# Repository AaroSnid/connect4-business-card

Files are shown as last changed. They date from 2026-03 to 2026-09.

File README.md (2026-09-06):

# Connect 4 Business Card

This business card doubles as a portable, handheld gaming device that allows a user to play game of Connect 4 against an onboard AI bot. Built on the STM32 platform, it features a custom 7x6 bicolor LED grid and a low-leakage power system designed for maximizing battery life.

> **Status:** Hardware V1.0 Release 
> **Hardware Version:** V1.0

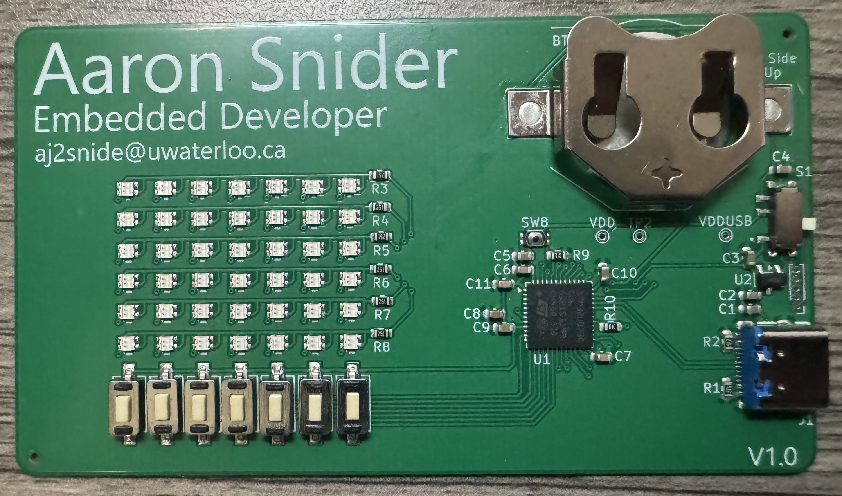
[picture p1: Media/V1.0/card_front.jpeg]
PCB V1.0 Front Image


---

## Features

- **Strategic Gameplay**
  - Play against a programmed AI bot on a microcontroller. You can select the difficulty and starting player through startup configurations.
  - 7x6 bicolor LED grid representing the game board. Player pieces are shown in Red / Orange

- **Dual Power Options**
  - **Battery Mode:** Optimized for a CR2032 coin cell for maximum portability.
  - **High-Performance Mode:** USB-C power input automatically boosts clock frequency for faster AI move processing. (Upcoming)

- **Power Management**
  - Physical slide switch for hard battery disconnection to prevent leakage current.
  - Integrated under-voltage and brown-out protection (BOR/POR/PDR).

- **Advanced Display Control**
  - 42 bicolor LEDs (84 total elements) routed antiparallel for layout efficiency.
  - Hardware-accelerated screen refreshing using timer triggered DMA writes to minimize CPU overhead.

- **Optimized Inputs**
  - 7 dedicated column buttons for move selection.
  - Software debouncing by limiting input registration windows.

---

## Bill of Materials (Summary)

| Item | Part Number | Qty | Notes |
|---|---|-----|---|
| MCU | STM32U073CCU6 | 1 | Ultra-low-power ARM Cortex-M0+ |
| Bicolor LEDs | P4-1615ROTCA1-0.6T | 42  | Red/Orange SMD LEDs |
| Battery Holder | Keystone 3002 | 1 | For CR2032 Coin Cell |
| USB-C Connector  | SHOU HAN C2765186 | 1 | 16-pin Power/Data Delivery |
| LDO Regulator | MCP1700T-3002E/TT | 1 | Low Quiescent Current 3.0V |
| Input Buttons | TSB008A2518A | 7 | Ultra-thin NO buttons |
| Power Switch | MSK12C02-HB | 1 | Battery/USB-C Selection |

---

## Hardware Subsystems

### Power Supply

- **Primary:** CR2032 Coin Cell.
- **Secondary:** USB-C (5V) regulated through an MCP1700 LDO.
- **Switching:** A physical SPDT switch toggles between sources. The "ON" position selects the battery, while "OFF" selects USB-C, ensuring the battery is physically disconnected when using external power.
- **Monitoring:** The STM32 utilizes its internal POR/PDR/BOR peripherals to monitor voltage levels and provide under-voltage protection.

---

### Microcontroller (STM32U073CCU6)

- **Architecture:** Ultra-low-power high-performance MCU.
- **Clock Management:** (Upcoming)
  - **Battery Mode:** Lower frequency to conserve energy.
  - **USB Mode:** Increased clock frequency for "intense" AI computation.

**Key Peripherals**

| Function | Peripheral | Notes |
|---|---|---|
| LED Matrix | GPIO Port B | Direct register writes for speed |
| Refresh Timing | Hardware Timer  | Triggers DMA transfers |
| Data Transfer | DMA | Automated GPIO updates |
| User Inputs | EXTI (1-7) | Pull-down resistors on Port A |
| Firmware Update  | USB-C (DFU) | Native USB 2.0 bootloader support |
| Debug | SWD | Standard programming interface |

---

### Display Implementation

The display consists of 42 bicolor LEDs wired in an antiparallel configuration.
- **Efficiency:** LEDs share pins to reduce the required GPIO count.
- **Refresh Logic:** A hardware timer triggers a DMA stream that performs direct register writes to GPIO Port B. This ensures a flicker-free display without taxing the main CPU core.

---

### Inputs & UI

- **Buttons:** 7 tactile switches corresponding to the 7 columns of the Connect 4 board.
- **Debouncing:** Handled via software flags within an Interrupt Service Routine (ISR). The system clears the flag just before the player turn for software input debouncing.

---

## Firmware Architecture

### Overview

The firmware is designed for efficiency and responsiveness. 
On startup, the MCU reads the buttons to get startup config values. The rightmost button will select the AI going first, and the others select the difficulty from 1-6 (default 5)
The main game loop handles the Connect-4 logic, while the display refresh is handled entirely in the background via timer triggered DMA.

### Programming

- **Debug:** A standard SWD header is provided for real-time debugging and initial flashing.

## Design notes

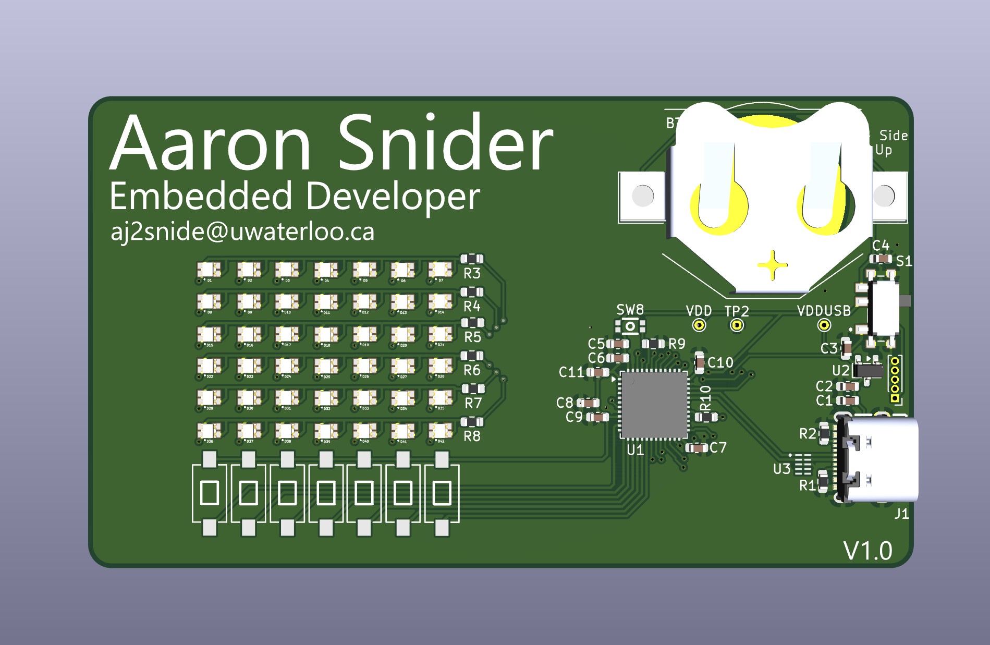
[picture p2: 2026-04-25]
KiCAD_files/V1.X/images/pcb_3D_model_V1.0.png

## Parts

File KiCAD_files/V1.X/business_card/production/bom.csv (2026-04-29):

Designator | Footprint | Quantity | Value | LCSC Part #
BT1 | BatteryHolder_Keystone_3002_1x2032 | 1 | CR2032
C1, C10, C5 | 0603 | 3 | 4.7uF
C11, C6, C7 | 0603 | 3 | 100nF
C2, C3, C4, C9 | 0603 | 4 | 1uF
C8 | 0603 | 1 | 10nF
D1, D10, D11, D12, D13, D14, D15, D16, D17, D18, D19, D2, D20, D21, D22, D23, D24, D25, D26, D27, D28, D29, D3, D30, D31, D32, D33, D34, D35, D36, D37, D38, D39, D4, D40, D41, D42, D5, D6, D7, D8, D9 | LED_CHIP | 42 | ~
J1 | USB-C-SMD_TYPE-C-6PIN-2MD-073 | 1 | USB_C_Receptacle_USB2.0_14P
J2 | PinHeader_1x05_P1.00mm_Vertical | 1 | Conn_01x05_Pin
R1, R2 | 0603 | 2 | 5.1K
R10, R9 | 0603 | 2 | 10K
R3, R4, R5, R6, R7, R8 | 0603 | 6 | 250
S1 | SW_MSK12C02 | 1 | MSK12C02
SW1, SW2, SW3, SW4, SW5, SW6, SW7 | TSB008A2526A | 7 | SW_Push
SW8 | SW-SMD_4P-L2.6-W1.6-P0.75-LS3.0 | 1 | SW_MEC_5E
TP1 | TestPoint_THTPad_D1.0mm_Drill0.5mm | 1 | VDDUSB
TP2 | TestPoint_THTPad_D1.0mm_Drill0.5mm | 1 | GND
TP3 | TestPoint_THTPad_D1.0mm_Drill0.5mm | 1 | VDD
U1 | QFN-48-1EP_7x7mm_P0.5mm_EP5.6x5.6mm | 1 | STM32U073CCUx
U2 | SOT-23 | 1 | MCP1700x-300xxTT

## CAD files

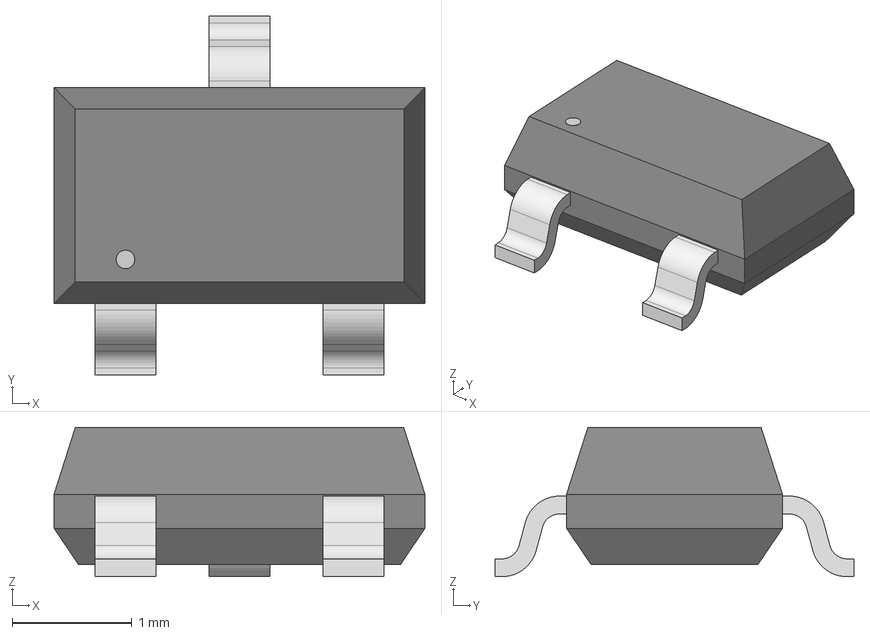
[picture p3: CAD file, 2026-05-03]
KiCAD_files/external_parts/AO3401A/SOT-23-3L_AOS.step
3.10 x 3.00 x 1.25 mm

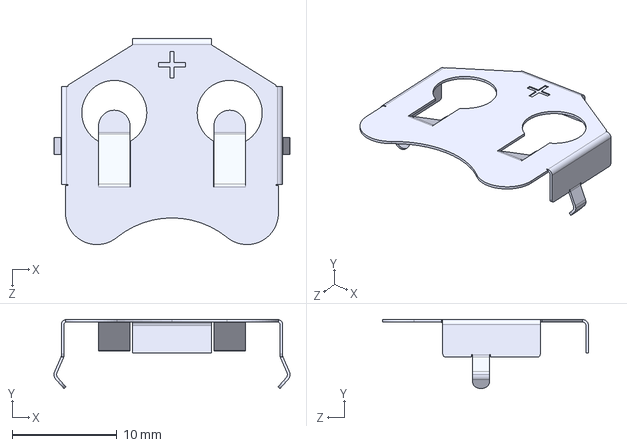
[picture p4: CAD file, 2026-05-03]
KiCAD_files/external_parts/BAT_HLD_005_THM/BAT-HLD-005-THM.step
22.5 x 6.59 x 19.6 mm

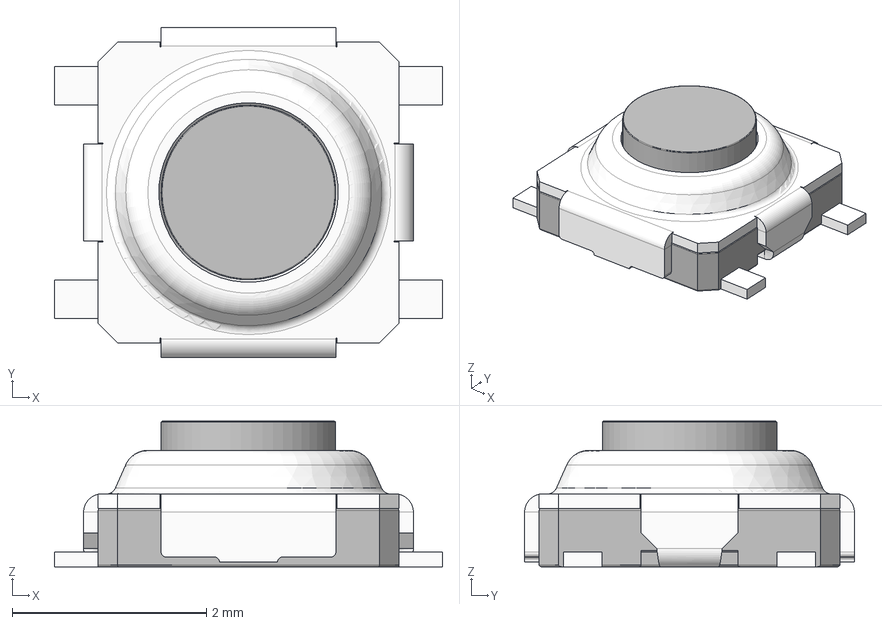
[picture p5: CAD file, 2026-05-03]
KiCAD_files/external_parts/CS1210F260/CS1210F260.stp
4.00 x 3.40 x 1.50 mm
Housing
Cover
Actuator
Terminal x 3
Terminal_MIR

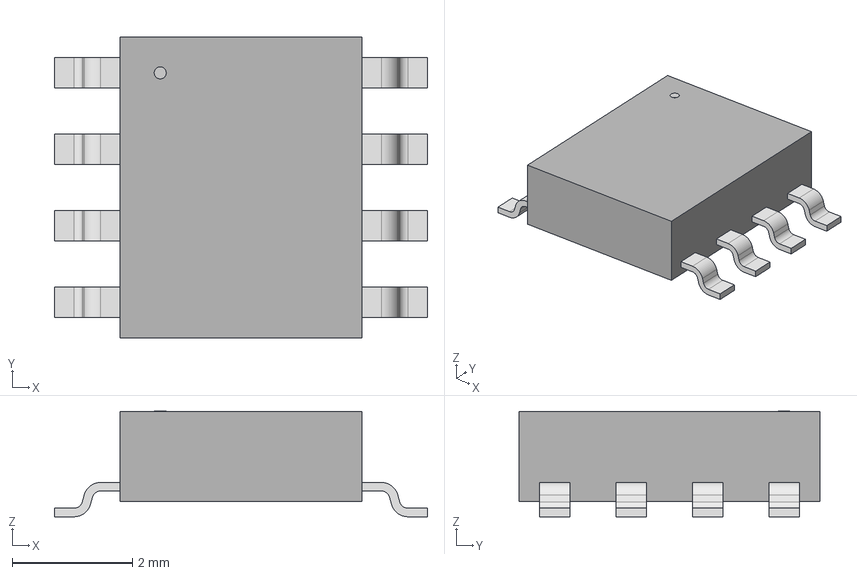
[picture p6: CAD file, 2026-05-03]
KiCAD_files/external_parts/ST25DV04KC-IE6S3/SO-8_STM.step
6.20 x 5.00 x 1.75 mm

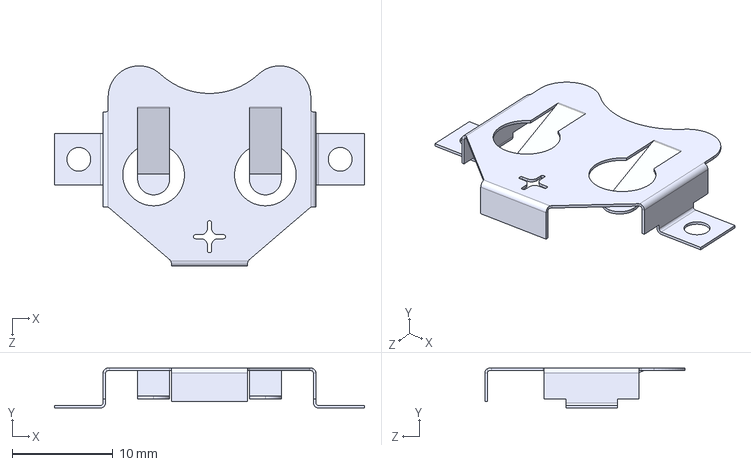
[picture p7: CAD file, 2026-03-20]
KiCAD_files/V1.X/external_parts/keystone_3002/3002.STEP
30.7 x 3.96 x 19.9 mm

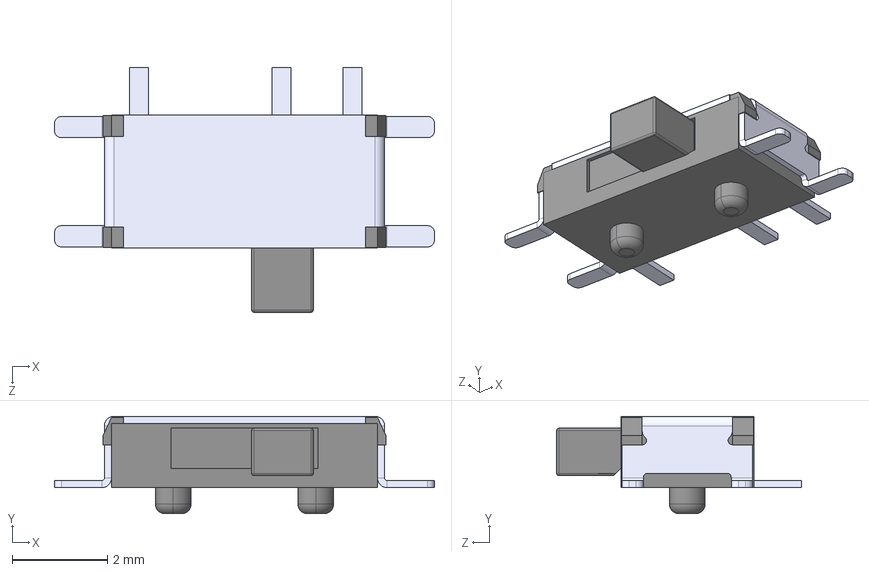
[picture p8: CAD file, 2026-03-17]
KiCAD_files/V1.X/external_parts/MSK12C02/MSK12C02.step
8.00 x 2.05 x 5.15 mm

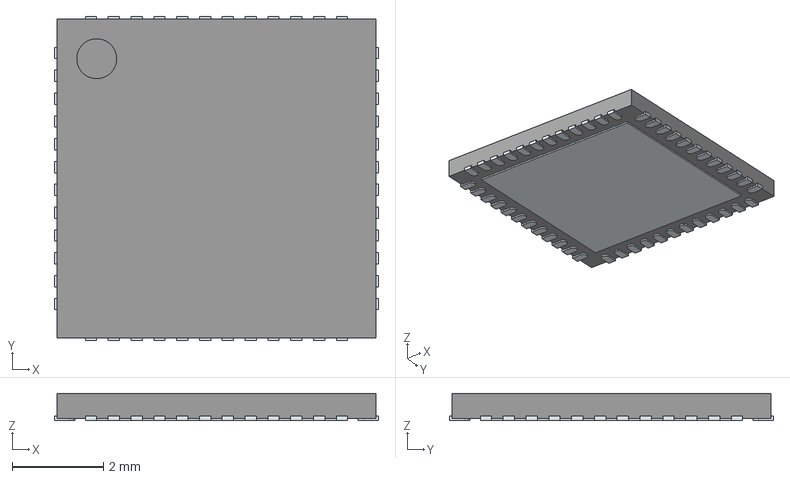
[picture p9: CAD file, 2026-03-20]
KiCAD_files/V1.X/external_parts/STM32U073CCU6/STM32U073CCU6.stp
7.10 x 7.10 x 0.6 mm
ThermalPin
PinsArrayLR
PinsArrayTB

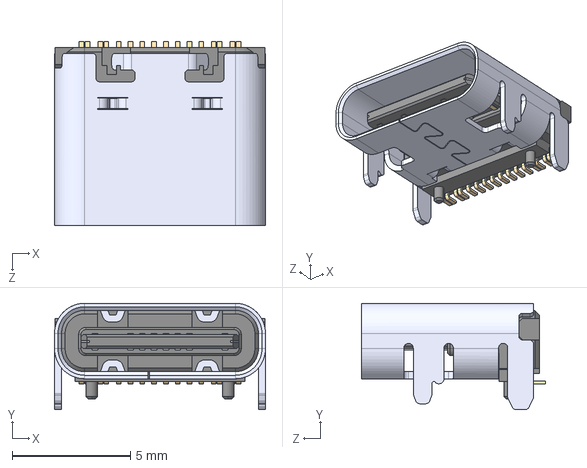
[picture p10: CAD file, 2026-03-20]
KiCAD_files/V1.X/external_parts/ul_TYPE-C16PIN/KH-TYPE-C-16P--3DModel-STEP-269445.STEP
8.94 x 4.51 x 7.81 mm

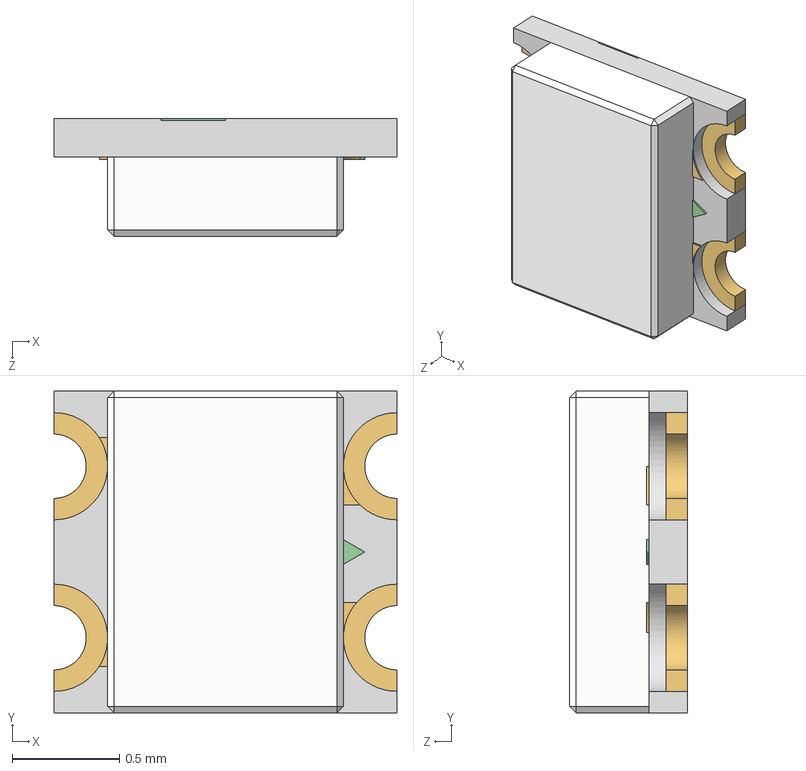
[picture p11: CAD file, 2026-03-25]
KiCAD_files/V1.X/external_parts/User Library-LED_0605-2.STEP
1.60 x 1.50 x 0.55 mm
DIODE

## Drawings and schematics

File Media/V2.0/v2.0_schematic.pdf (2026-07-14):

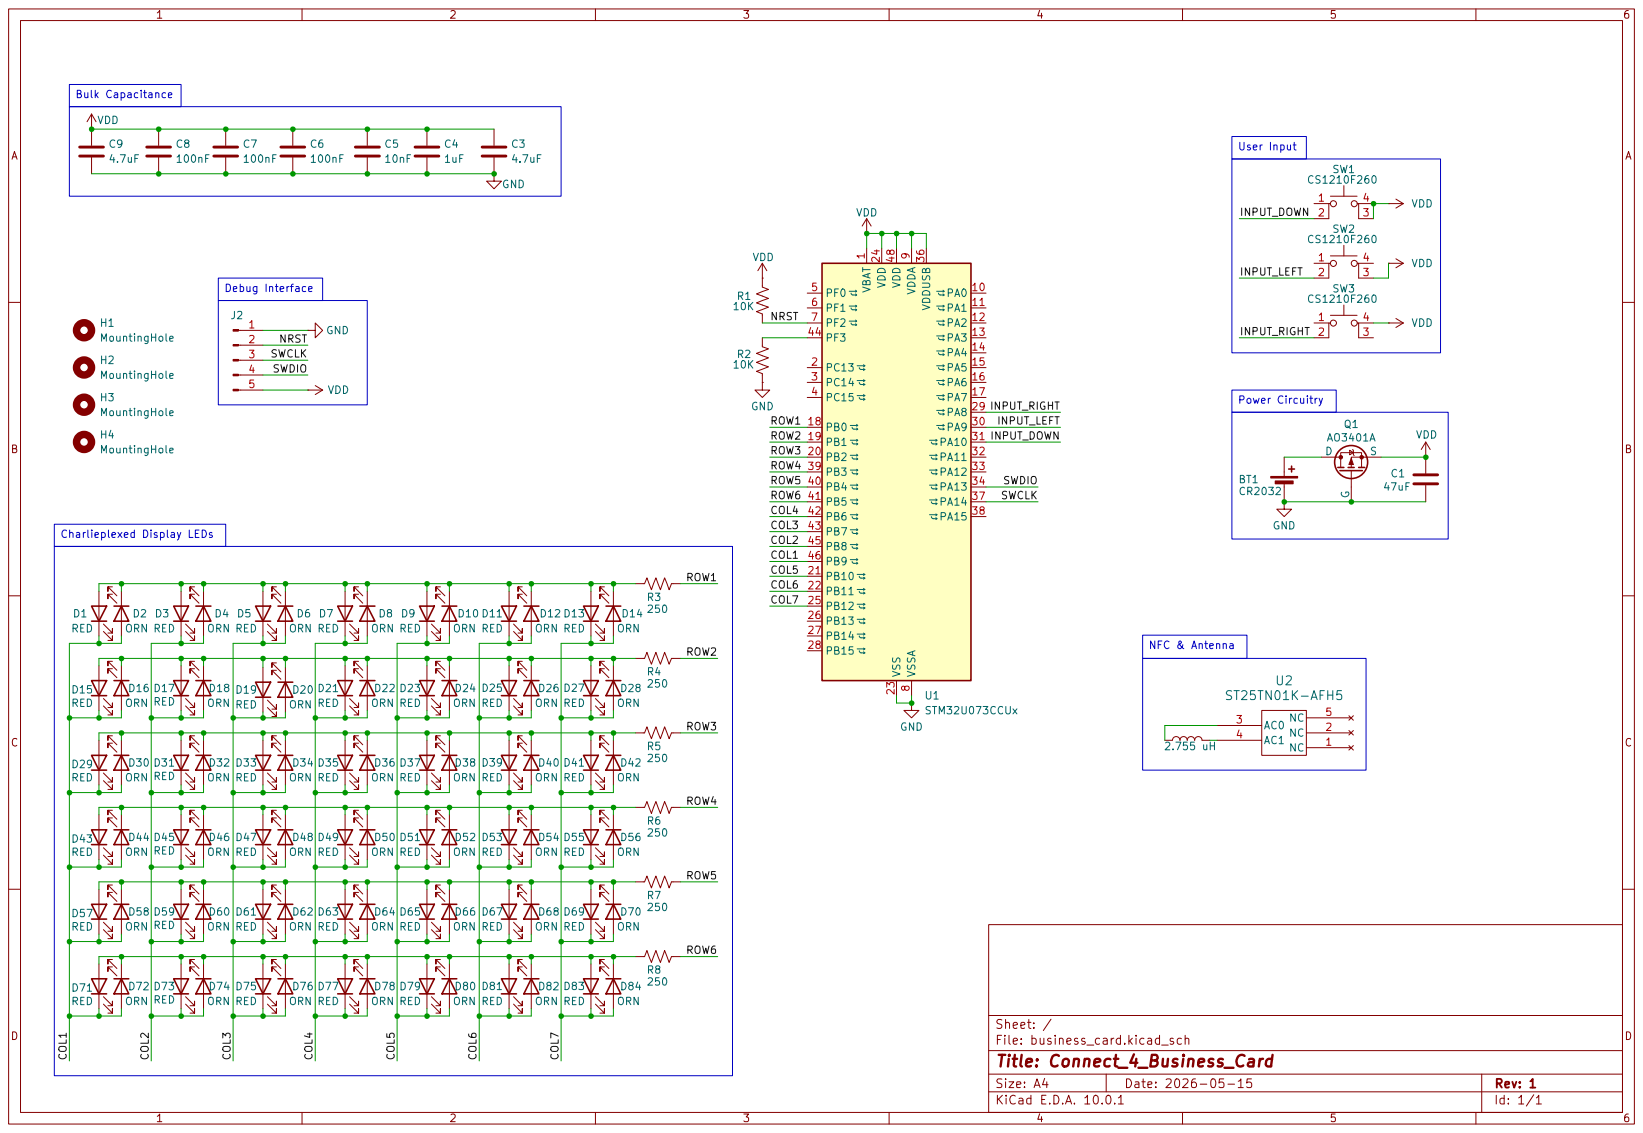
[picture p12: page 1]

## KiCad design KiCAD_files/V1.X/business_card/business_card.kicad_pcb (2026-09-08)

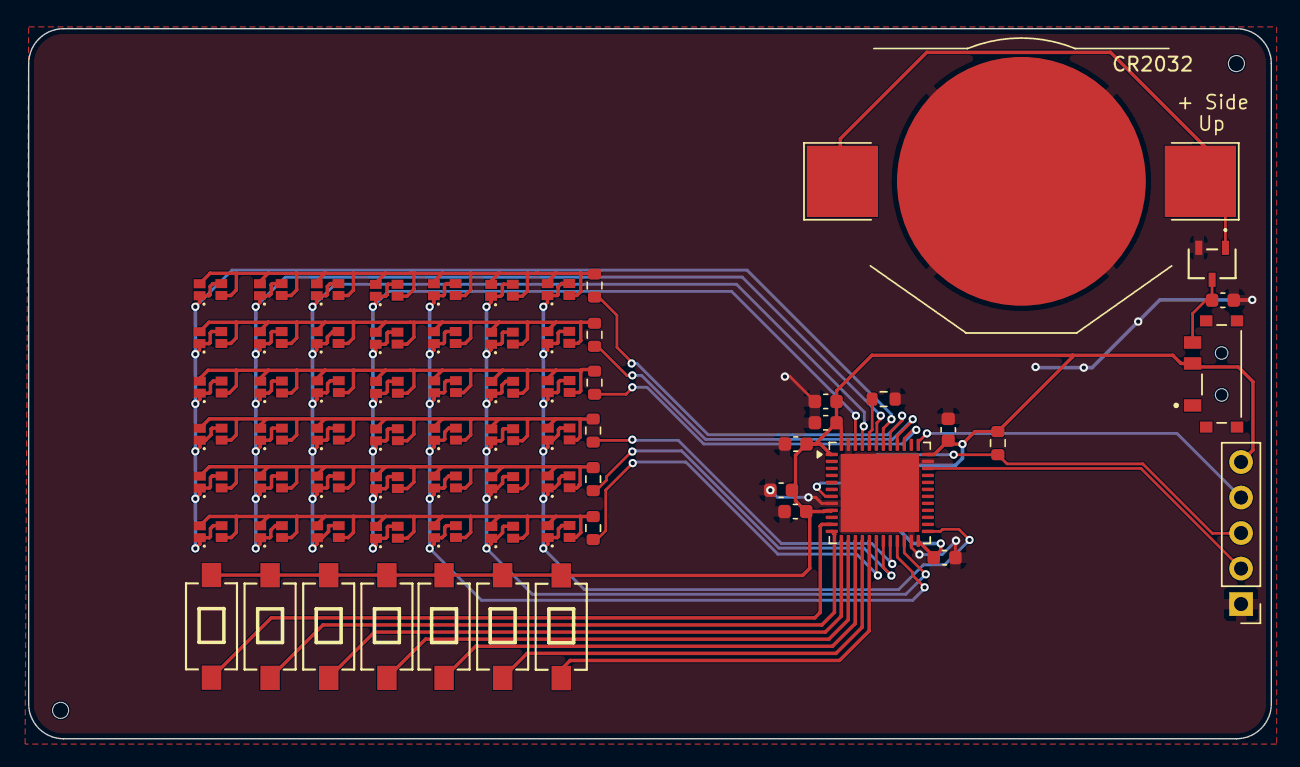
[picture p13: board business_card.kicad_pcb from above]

Board: 2 copper layers, 88.9 x 50.8 mm, 72 parts (0 on the bottom side), 35 nets.

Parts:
BT1: CR2032; BatteryHolder_Keystone_3002_1x2032
C1: 47uF; C_0603_1608Metric
C5, C10: 4.7uF; C_0603_1608Metric
C6, C7, C11: 100nF; C_0603_1608Metric
C8: 10nF; C_0603_1608Metric
C9: 1uF; C_0603_1608Metric
D1, D2, D3, D4, D5, D6, D7, D8, D9, D10, D11, D12, D13, D14, D15, D16, D17, D18, D19, D20, D21, D22, D23, D24, D25, D26, D27, D28, D29, D30, D31, D32, D33, D34, D35, D36, D37, D38, D39, D40, D41, D42: LED_CHIP
H1, H1#2: MountingHole; ToolingHole_1.152mm
J2: Conn_01x05_Pin; PinHeader_1x05_P2.54mm_Vertical
Q1: AO3401A; SOT-23-3L_AOS-L
R3, R4, R5, R6, R7, R8: 250; R_0603_1608Metric
R9, R10: 10K; R_0603_1608Metric
S1: MSK12C02; SW_MSK12C02
SW1, SW2, SW3, SW4, SW5, SW6, SW7: SW_Push; TSB008A2526A
U1: STM32U073CCUx; QFN-48-1EP_7x7mm_P0.5mm_EP5.6x5.6mm

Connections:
/COL1: D1.1, D1.3, D8.1, D8.3, D15.1, D15.3, D22.1, D22.3, D29.1, D29.3, D36.1, D36.3, U1.42 (PB6)
/COL2: D2.1, D2.3, D9.1, D9.3, D16.1, D16.3, D23.1, D23.3, D30.1, D30.3, D37.1, D37.3, U1.43 (PB7)
/COL3: D3.1, D3.3, D10.1, D10.3, D17.1, D17.3, D24.1, D24.3, D31.1, D31.3, D38.1, D38.3, U1.45 (PB8)
/COL4: D4.1, D4.3, D11.1, D11.3, D18.1, D18.3, D25.1, D25.3, D32.1, D32.3, D39.1, D39.3, U1.46 (PB9)
/COL5: D5.1, D5.3, D12.1, D12.3, D19.1, D19.3, D26.1, D26.3, D33.1, D33.3, D40.1, D40.3, U1.21 (PB10)
/COL6: D6.1, D6.3, D13.1, D13.3, D20.1, D20.3, D27.1, D27.3, D34.1, D34.3, D41.1, D41.3, U1.22 (PB11)
/COL7: D7.1, D7.3, D14.1, D14.3, D21.1, D21.3, D28.1, D28.3, D35.1, D35.3, D42.1, D42.3, U1.25 (PB12)
/INPUT_1: SW1.1, U1.11 (PA1)
/INPUT_2: SW2.1, U1.12 (PA2)
/INPUT_3: SW3.1, U1.13 (PA3)
/INPUT_4: SW4.1, U1.14 (PA4)
/INPUT_5: SW5.1, U1.15 (PA5)
/INPUT_6: SW6.1, U1.16 (PA6)
/INPUT_7: SW7.1, U1.17 (PA7)
/NRST: J2.3, R10.2, U1.7 (PF2)
/ROW1: R3.2, U1.41 (PB5)
/ROW2: R4.2, U1.40 (PB4)
/ROW3: R5.2, U1.39 (PB3)
/ROW4: R6.2, U1.20 (PB2)
/ROW5: R7.2, U1.19 (PB1)
/ROW6: R8.2, U1.18 (PB0)
/SWCLK: J2.4, U1.37 (PA14)
/SWDIO: J2.2, U1.34 (PA13)
GND: BT1.2 (-), C1.2, C5.2, C6.2, C7.2, C8.2, C9.2, C10.2, C11.2, J2.1, Q1.2 (G), R9.2, U1.8 (VSSA), U1.23 (VSS), U1.35 (VSS), U1.47 (VSS), U1.49 (VSS)
unnamed: BT1.1 (+), Q1.1 (D)
unnamed: D1.2, D1.4, D2.2, D2.4, D3.2, D3.4, D4.2, D4.4, D5.2, D5.4, D6.2, D6.4, D7.2, D7.4, R3.1
unnamed: D8.2, D8.4, D9.2, D9.4, D10.2, D10.4, D11.2, D11.4, D12.2, D12.4, D13.2, D13.4, D14.2, D14.4, R4.1
unnamed: D15.2, D15.4, D16.2, D16.4, D17.2, D17.4, D18.2, D18.4, D19.2, D19.4, D20.2, D20.4, D21.2, D21.4, R5.1
unnamed: D22.2, D22.4, D23.2, D23.4, D24.2, D24.4, D25.2, D25.4, D26.2, D26.4, D27.2, D27.4, D28.2, D28.4, R6.1
unnamed: D29.2, D29.4, D30.2, D30.4, D31.2, D31.4, D32.2, D32.4, D33.2, D33.4, D34.2, D34.4, D35.2, D35.4, R7.1
unnamed: D36.2, D36.4, D37.2, D37.4, D38.2, D38.4, D39.2, D39.4, D40.2, D40.4, D41.2, D41.4, D42.2, D42.4, R8.1
unnamed: C1.1, Q1.3 (S), S1.3
unnamed: S1.4_1 (GND), S1.4_2 (GND), S1.4_3 (GND), S1.4_4 (GND)
unnamed: R9.1, U1.44 (PF3)
VDD: C5.1, C6.1, C7.1, C8.1, C9.1, C10.1, C11.1, J2.5, R10.1, S1.2, SW1.2, SW2.2, SW3.2, SW4.2, SW5.2, SW6.2, SW7.2, U1.1 (VBAT), U1.9 (VDDA), U1.24 (VDD), U1.36 (VDDUSB), U1.48 (VDD)

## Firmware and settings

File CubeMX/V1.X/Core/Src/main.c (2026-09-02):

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
/* Includes ------------------------------------------------------------------*/
#include "main.h"

/* USER CODE BEGIN Includes */

#include <stdbool.h>
#include "connect-4-board.h"

/* USER CODE END Includes */

/* USER CODE BEGIN PD */

#define MODER_REG_INPUT   0x00000000U  // [1:0] = 00 == Input
#define MODER_REG_OUTPUT  0x55555555U  // [1:0] = 01 == Output

// These represent GPIO pin numbers in port B, which could change between hardware versions
#define ROW_6_POS         0U
#define ROW_5_POS         1U
#define ROW_4_POS         2U
#define ROW_3_POS         3U
#define ROW_2_POS         4U
#define ROW_1_POS         5U

#define COL_1_POS         6U
#define COL_2_POS         7U
#define COL_3_POS         8U
#define COL_4_POS         9U
#define COL_5_POS         10U
#define COL_6_POS         11U
#define COL_7_POS         12U

// ODR bits (16 bit reg)
// Bit operations are taken care of by compiler, so at runtime it will be a constant
#define ROW_6_ODR         ((uint16_t)(1U << ROW_6_POS))

#define COL_1_ODR         ((uint16_t)(1U << COL_1_POS))

// MODER bits (32 bit reg)
#define ROW_6_MODER       ((uint32_t)(0x3UL << (ROW_6_POS * 2)))
#define ROW_5_MODER       ((uint32_t)(0x3UL << (ROW_5_POS * 2)))
#define ROW_4_MODER       ((uint32_t)(0x3UL << (ROW_4_POS * 2)))
#define ROW_3_MODER       ((uint32_t)(0x3UL << (ROW_3_POS * 2)))
#define ROW_2_MODER       ((uint32_t)(0x3UL << (ROW_2_POS * 2)))
#define ROW_1_MODER       ((uint32_t)(0x3UL << (ROW_1_POS * 2)))

#define COL_1_MODER       ((uint32_t)(0x3UL << (COL_1_POS * 2)))
#define COL_2_MODER       ((uint32_t)(0x3UL << (COL_2_POS * 2)))
#define COL_3_MODER       ((uint32_t)(0x3UL << (COL_3_POS * 2)))
#define COL_4_MODER       ((uint32_t)(0x3UL << (COL_4_POS * 2)))
#define COL_5_MODER       ((uint32_t)(0x3UL << (COL_5_POS * 2)))
#define COL_6_MODER       ((uint32_t)(0x3UL << (COL_6_POS * 2)))
#define COL_7_MODER       ((uint32_t)(0x3UL << (COL_7_POS * 2)))
/* USER CODE END PD */

/* USER CODE BEGIN PM */

#define EXTI_LINES_1_7_MASK    (EXTI_IMR1_IM1 | EXTI_IMR1_IM2 | EXTI_IMR1_IM3 | \
                                EXTI_IMR1_IM4 | EXTI_IMR1_IM5 | EXTI_IMR1_IM6 | \
                                EXTI_IMR1_IM7)

#define EXTI_LINES_1_7_PENDING (EXTI_RPR1_RPIF1 | EXTI_RPR1_RPIF2 | EXTI_RPR1_RPIF3 | \
                                EXTI_RPR1_RPIF4 | EXTI_RPR1_RPIF5 | EXTI_RPR1_RPIF6 | \
                                EXTI_RPR1_RPIF7)

/* USER CODE END PM */


TIM_HandleTypeDef htim2;
DMA_HandleTypeDef hdma_tim2_ch1;
DMA_HandleTypeDef hdma_tim2_ch2;

/* USER CODE BEGIN PV */

volatile uint8_t player_button_input = 0U; // Stores pressed button ID (1-7). 0 means no input.
volatile bool input_received = false;      // Flag to signal the game loop

volatile uint32_t gpiob_pin_modes[42] = {
    (ROW_6_MODER | COL_1_MODER) & MODER_REG_OUTPUT, // Bitboard 0 (Bottom Left)
    (ROW_5_MODER | COL_1_MODER) & MODER_REG_OUTPUT, // Bitboard 1
    (ROW_4_MODER | COL_1_MODER) & MODER_REG_OUTPUT, // Bitboard 2
    (ROW_3_MODER | COL_1_MODER) & MODER_REG_OUTPUT, // etc
    (ROW_2_MODER | COL_1_MODER) & MODER_REG_OUTPUT,
    (ROW_1_MODER | COL_1_MODER) & MODER_REG_OUTPUT,

    (ROW_6_MODER | COL_2_MODER) & MODER_REG_OUTPUT,
    (ROW_5_MODER | COL_2_MODER) & MODER_REG_OUTPUT,
    (ROW_4_MODER | COL_2_MODER) & MODER_REG_OUTPUT,
    (ROW_3_MODER | COL_2_MODER) & MODER_REG_OUTPUT,
    (ROW_2_MODER | COL_2_MODER) & MODER_REG_OUTPUT,
    (ROW_1_MODER | COL_2_MODER) & MODER_REG_OUTPUT,

    (ROW_6_MODER | COL_3_MODER) & MODER_REG_OUTPUT,
    (ROW_5_MODER | COL_3_MODER) & MODER_REG_OUTPUT,
    (ROW_4_MODER | COL_3_MODER) & MODER_REG_OUTPUT,
    (ROW_3_MODER | COL_3_MODER) & MODER_REG_OUTPUT,
    (ROW_2_MODER | COL_3_MODER) & MODER_REG_OUTPUT,
    (ROW_1_MODER | COL_3_MODER) & MODER_REG_OUTPUT,

    (ROW_6_MODER | COL_4_MODER) & MODER_REG_OUTPUT,
    (ROW_5_MODER | COL_4_MODER) & MODER_REG_OUTPUT,
    (ROW_4_MODER | COL_4_MODER) & MODER_REG_OUTPUT,
    (ROW_3_MODER | COL_4_MODER) & MODER_REG_OUTPUT,
    (ROW_2_MODER | COL_4_MODER) & MODER_REG_OUTPUT,
    (ROW_1_MODER | COL_4_MODER) & MODER_REG_OUTPUT,

    (ROW_6_MODER | COL_5_MODER) & MODER_REG_OUTPUT,
    (ROW_5_MODER | COL_5_MODER) & MODER_REG_OUTPUT,
    (ROW_4_MODER | COL_5_MODER) & MODER_REG_OUTPUT,
    (ROW_3_MODER | COL_5_MODER) & MODER_REG_OUTPUT,
    (ROW_2_MODER | COL_5_MODER) & MODER_REG_OUTPUT,
    (ROW_1_MODER | COL_5_MODER) & MODER_REG_OUTPUT,

    (ROW_6_MODER | COL_6_MODER) & MODER_REG_OUTPUT,
    (ROW_5_MODER | COL_6_MODER) & MODER_REG_OUTPUT,
    (ROW_4_MODER | COL_6_MODER) & MODER_REG_OUTPUT,
    (ROW_3_MODER | COL_6_MODER) & MODER_REG_OUTPUT,
    (ROW_2_MODER | COL_6_MODER) & MODER_REG_OUTPUT,
    (ROW_1_MODER | COL_6_MODER) & MODER_REG_OUTPUT,

    (ROW_6_MODER | COL_7_MODER) & MODER_REG_OUTPUT,
    (ROW_5_MODER | COL_7_MODER) & MODER_REG_OUTPUT,
    (ROW_4_MODER | COL_7_MODER) & MODER_REG_OUTPUT,
    (ROW_3_MODER | COL_7_MODER) & MODER_REG_OUTPUT,
    (ROW_2_MODER | COL_7_MODER) & MODER_REG_OUTPUT,
    (ROW_1_MODER | COL_7_MODER) & MODER_REG_OUTPUT
};

volatile uint16_t gpiob_output_data[42] = {0U};  // Cast to uint32_t with 0-extension before writing into reg

uint64_t game_board = 0U;
uint64_t p1_moves = 0U;
uint8_t move_num = 0U;
extern unsigned int MINIMAX_MAX_DEPTH;
void (*player_color_set)(uint8_t);
void (*ai_color_set)(uint8_t);

/* USER CODE END PV */

void SystemClock_Config(void);
static void MX_GPIO_Init(void);
static void MX_DMA_Init(void);
static void MX_TIM2_Init(void);
/* USER CODE BEGIN PFP */

static void unified_button_handler(uint32_t pending_register) {
    
    EXTI->RPR1 = pending_register;
  
    if ((!input_received) && (pending_register != 0U)) {
        // Find interrupt source by counting trailing zeros to get lowest bit index
        player_button_input = (uint8_t)__builtin_ctz(pending_register);
        input_received = true;
    }
}

// Expected function signatures for interrupt callbacks
void EXTI0_1_IRQHandler(void) {
    unified_button_handler(EXTI->RPR1);
}

void EXTI2_3_IRQHandler(void) {
    unified_button_handler(EXTI->RPR1);
}

void EXTI4_15_IRQHandler(void) {
    unified_button_handler(EXTI->RPR1);
}

uint8_t bitboard_to_buffer_index(uint8_t bitboard_index) {
    return bitboard_index - (bitboard_index / 7);
}

// Leverage existing macros and shift relative to their positions
// Change operations to /6 and %6 if using buffer index
uint16_t get_row_odr(uint8_t bitboard_index) {
    // Bitboard index % 7 gives row 0 (bottom) to 5 (top)
    return (uint16_t)(ROW_6_ODR << (bitboard_index % 7));
}

uint16_t get_col_odr(uint8_t bitboard_index) {
    // Bitboard index / 7 gives col 0 to 6
    return (uint16_t)(COL_1_ODR << (bitboard_index / 7));
}

void set_color_row(uint8_t bitboard_position) {
    gpiob_output_data[bitboard_to_buffer_index(bitboard_position)] = get_row_odr(bitboard_position);
}

void set_color_col(uint8_t bitboard_position) {
    gpiob_output_data[bitboard_to_buffer_index(bitboard_position)] = get_col_odr(bitboard_position);
}

void set_color_none(uint8_t bitboard_position) {
    gpiob_output_data[bitboard_to_buffer_index(bitboard_position)] = 0U;
}

void flash_winning_moves(uint64_t game_board, bool is_player_win) {
    uint64_t winning_moves = isolate_winning_moves(game_board);
    uint8_t move_indices[4U]; // Note this intentionally has a maximum of 4 for simplicity
    void (*color_set_funct)(uint8_t);

    // Get winning bit indeces
    uint8_t count = 0U;
    for (uint8_t index = 0U; index < 64U && count < 4U; index++) {
        if ((winning_moves & (1ULL << index)) != 0U) {
            move_indices[count++] = index;
        }
    }

    // Get function pointer for correct color
    if (is_player_win){
        color_set_funct = &set_color_col;
    } else {
        color_set_funct = &set_color_row;
    }

    for (uint8_t i = 0; i < 4U; ++i) {

      set_color_none(move_indices[0]);
      set_color_none(move_indices[1]);
      set_color_none(move_indices[2]);
      set_color_none(move_indices[3]);

      HAL_Delay(500);

      color_set_funct(move_indices[0]);
      color_set_funct(move_indices[1]);
      color_set_funct(move_indices[2]);
      color_set_funct(move_indices[3]);

      HAL_Delay(500);
    }
}

void end_player_win(uint64_t game_board) {
    flash_winning_moves(game_board, true);
    HAL_Delay(3000);

}

void end_ai_win(uint64_t game_board) {
    flash_winning_moves(game_board, false);
    HAL_Delay(3000);
}

void clear_board(void) {
    for (uint8_t i = 0U; i < 42U; ++i) {
        gpiob_output_data[i] = 0U;
    }
}

/* USER CODE END PFP */

/**
  * @brief  The application entry point.
  * @retval int
  */
int main(void)
{

  /* MCU Configuration--------------------------------------------------------*/

  /* Reset of all peripherals, Initializes the Flash interface and the Systick. */
  HAL_Init();

  /* USER CODE BEGIN Init */

  // Power Supply Voltage Monitoring Configuration
  if ((FLASH->OPTR & FLASH_OPTR_BOR_LEV) != OB_BOR_LEVEL_1) {
      FLASH_OBProgramInitTypeDef OptionsBytesStruct = {0};

      // Clear a stale error
      __HAL_FLASH_CLEAR_FLAG(FLASH_FLAG_OPERR);

      HAL_FLASH_Unlock();
      HAL_FLASH_OB_Unlock();

      // Hardcoded payload for BOR Level 1
      OptionsBytesStruct.OptionType = OPTIONBYTE_USER;
      OptionsBytesStruct.USERType   = OB_USER_BOR_EN | OB_USER_BOR_LEV;
      OptionsBytesStruct.USERConfig = OB_BOR_ENABLE | OB_BOR_LEVEL_1;

      // Program and reload option bytes
      if (HAL_FLASHEx_OBProgram(&OptionsBytesStruct) == HAL_OK) {
          // Reboots device with new 2.2V threshold
          HAL_FLASH_OB_Launch();
      }
      // Option bytes programming has failed

      // Volatile to prevent optimizing out
      // To be read on debug
      // volatile uint32_t flash_error = HAL_FLASH_GetError();

      // Fallback safety locks
      HAL_FLASH_OB_Lock();
      HAL_FLASH_Lock();

      Error_Handler();
  }

  // Enable BOR/PVD Periodic Sampling
  // Enable Power interface clock
  SET_BIT(RCC->APBENR1, RCC_APBENR1_PWREN);
    
  // Enable ultra-low-power sampling
  SET_BIT(PWR->CR3, PWR_CR3_ENULP);

  /* USER CODE END Init */

  /* Configure the system clock */
  SystemClock_Config();

  /* Initialize all configured peripherals */
  MX_GPIO_Init();
  MX_DMA_Init();
  MX_TIM2_Init();
  /* USER CODE BEGIN 2 */

  // DMA channel driving GPIOB ODR
  hdma_tim2_ch1.Instance = DMA1_Channel1;
  hdma_tim2_ch1.Init.Request = DMA_REQUEST_TIM2_UP;
  hdma_tim2_ch1.Init.Direction = DMA_MEMORY_TO_PERIPH;
  hdma_tim2_ch1.Init.PeriphInc = DMA_PINC_DISABLE;
  hdma_tim2_ch1.Init.MemInc = DMA_MINC_ENABLE;
  hdma_tim2_ch1.Init.PeriphDataAlignment = DMA_PDATAALIGN_HALFWORD;
  hdma_tim2_ch1.Init.MemDataAlignment = DMA_MDATAALIGN_HALFWORD;
  hdma_tim2_ch1.Init.Mode = DMA_CIRCULAR;
  hdma_tim2_ch1.Init.Priority = DMA_PRIORITY_HIGH;
  if (HAL_DMA_Init(&hdma_tim2_ch1) != HAL_OK) { 
      Error_Handler();
  }

  // DMA channel driving GPIOB MODER
  hdma_tim2_ch2.Instance = DMA1_Channel2;
  hdma_tim2_ch2.Init.Request = DMA_REQUEST_TIM2_UP;
  hdma_tim2_ch2.Init.Direction = DMA_MEMORY_TO_PERIPH;
  hdma_tim2_ch2.Init.PeriphInc = DMA_PINC_DISABLE;
  hdma_tim2_ch2.Init.MemInc = DMA_MINC_ENABLE;
  hdma_tim2_ch2.Init.PeriphDataAlignment = DMA_PDATAALIGN_WORD;
  hdma_tim2_ch2.Init.MemDataAlignment = DMA_MDATAALIGN_WORD;
  hdma_tim2_ch2.Init.Mode = DMA_CIRCULAR;
  hdma_tim2_ch2.Init.Priority = DMA_PRIORITY_HIGH;
  if (HAL_DMA_Init(&hdma_tim2_ch2) != HAL_OK) { 
      Error_Handler();
  }

  // Point DMA to screen buffers and the respective PortB registers
  HAL_DMA_Start(&hdma_tim2_ch2, (uint32_t)gpiob_pin_modes, (uint32_t)&(GPIOB->MODER), 42);
  HAL_DMA_Start(&hdma_tim2_ch1, (uint32_t)gpiob_output_data, (uint32_t)&(GPIOB->ODR), 42);

  // Enable the Timer to trigger DMA updates
  __HAL_TIM_ENABLE_DMA(&htim2, TIM_DMA_UPDATE);
    
  HAL_TIM_Base_Start(&htim2);

  // Signal successful startup, sampling user configurations
  set_color_row(5);

  HAL_Delay(500);

  // Config parameters as follows:
  // Inputs [1:6] - AI recursion depth  (default: 5)
  // Input  [7]   - AI starts           (default: false)
  uint32_t config_parameters = GPIOA->IDR;

  // Shift by 1 so first button aligns to bit 0
  uint32_t depth_buttons = (config_parameters >> 1) & 0x3F;

  if (depth_buttons != 0U) {
      MINIMAX_MAX_DEPTH = __builtin_ctz(depth_buttons) + 1;
  }

  // Set first player move color
  if ((config_parameters & (1U << 7)) != 0U) {
      // Offset move number so that AI goes first
      move_num = 1;

      player_color_set = &set_color_row;
      ai_color_set = &set_color_col;
  } else {
    player_color_set = &set_color_col;
    ai_color_set = &set_color_row;
  }

  set_color_none(5);

  /* USER CODE END 2 */

  /* Infinite loop */
  /* USER CODE BEGIN WHILE */
  while (1)
  {
    while (!is_full(game_board))
    {
      if (move_num % 2 == 0)
      {
        uint8_t column;
        int location;

        for (;;) {
          player_button_input = 0;
          input_received = false;

          while (!input_received) {
            __WFI(); // TODO: Give AI additional computation time during wait
          }

          if (player_button_input < 1 || player_button_input > 7) {
            continue;
          }
          column = player_button_input - 1;

          if (is_playable(game_board, column)) {
            break;
          }
        }

        location = play_move(&game_board, column);
        if (location < 0) {
          break;
        }

        player_color_set(location);

        p1_moves |= (1ULL << location);
        move_num++;

        if (is_won(p1_moves)) {
          break;
        }
      }
      else
      {
        int bot_column = choose_best_ai_move(game_board, p1_moves);
        if (bot_column < 0) {
          break;
        }

        int location = play_move(&game_board, (uint8_t)bot_column);
        if (location < 0) {
          break;
        }

        ai_color_set(location);

        move_num++;

        if (is_won(game_board ^ p1_moves)) {
          break;
        }
      }
    }

    HAL_Delay(1000);

    if (is_won(p1_moves)) {
      end_player_win(p1_moves);
    }
    else if (is_won(game_board ^ p1_moves)) {
      end_ai_win(game_board ^ p1_moves);
    }

    game_board = 0;
    p1_moves = 0;
    move_num = 0;

    clear_board();

    /* USER CODE END WHILE */

    /* USER CODE BEGIN 3 */
  }
  /* USER CODE END 3 */
}

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


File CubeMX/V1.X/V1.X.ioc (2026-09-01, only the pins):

Mcu.UserName=STM32U073CCUx
PA1.GPIO_Label=INPUT_1
PA1.Signal=GPXTI1
PA2.GPIO_Label=INPUT_2
PA2.Signal=GPXTI2
PA3.GPIO_Label=INPUT_3
PA3.Signal=GPXTI3
PA4.GPIO_Label=INPUT_4
PA4.Signal=GPXTI4
PA5.GPIO_Label=INPUT_5
PA5.Signal=GPXTI5
PA6.GPIO_Label=INPUT_6
PA6.Signal=GPXTI6
PA7.GPIO_Label=INPUT_7
PA7.Signal=GPXTI7
PA8.GPIO_Label=USB_INPUT
PA8.Signal=GPIO_Input

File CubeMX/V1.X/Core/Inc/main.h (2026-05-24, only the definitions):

#define INPUT_1_Pin GPIO_PIN_1
#define INPUT_1_GPIO_Port GPIOA
#define INPUT_1_EXTI_IRQn EXTI0_1_IRQn
#define INPUT_2_Pin GPIO_PIN_2
#define INPUT_2_GPIO_Port GPIOA
#define INPUT_2_EXTI_IRQn EXTI2_3_IRQn
#define INPUT_3_Pin GPIO_PIN_3
#define INPUT_3_GPIO_Port GPIOA
#define INPUT_3_EXTI_IRQn EXTI2_3_IRQn
#define INPUT_4_Pin GPIO_PIN_4
#define INPUT_4_GPIO_Port GPIOA
#define INPUT_4_EXTI_IRQn EXTI4_15_IRQn
#define INPUT_5_Pin GPIO_PIN_5
#define INPUT_5_GPIO_Port GPIOA
#define INPUT_5_EXTI_IRQn EXTI4_15_IRQn
#define INPUT_6_Pin GPIO_PIN_6
#define INPUT_6_GPIO_Port GPIOA
#define INPUT_6_EXTI_IRQn EXTI4_15_IRQn
#define INPUT_7_Pin GPIO_PIN_7
#define INPUT_7_GPIO_Port GPIOA
#define INPUT_7_EXTI_IRQn EXTI4_15_IRQn
#define USB_INPUT_Pin GPIO_PIN_8
#define USB_INPUT_GPIO_Port GPIOA

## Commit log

2026-03-17 Initial Circuit Diagram For PCB
    [MSK12C02--3DModel-STEP-740413.STEP, MSK12C02.step, business_card.kicad_pcb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]
2026-03-17 Clean Up Files and Add Footprints
    [business_card.kicad_sch]
2026-03-17 Add Debug Interface and Test Points
    [business_card.kicad_sch]
2026-03-18 Update Footprints of Components and Start Layout Design
    [business_card.kicad_pcb, business_card.kicad_sch]
2026-03-19 Change Connections to Match STM32C0 Spec
    [business_card.kicad_pcb, business_card.kicad_sch]
2026-03-19 Move Battery Voltage Monitoring to Software
    [business_card.kicad_sch]
2026-03-20 Switch Button types, Add 3D Models to Components
    [3002.STEP, KH-TYPE-C-16P--3DModel-STEP-269445.STEP, STM32U073CCU6.stp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]
2026-03-25 PCB Layout
    [User Library-LED_0605-2.STEP, business_card.kicad_pcb, business_card.kicad_sch]
2026-03-25 Fix Edge Cuts
    [business_card.kicad_pcb]
2026-03-25 Fix Ground Fill
    [business_card.kicad_pcb]
2026-03-28 Finish Initial PCB Layout
    [business_card.kicad_pcb, business_card.kicad_sch]
2026-03-28 Fix Small Connection Issues
    [business_card.kicad_pcb]
2026-04-01 Add Contact Info
    [business_card.kicad_pcb, business_card.kicad_sch]
2026-04-29 V1.0 Hardware Production Version Out For Assembly
    [bom.csv, business_card.kicad_pcb, business_card.kicad_sch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]
2026-05-03 Initial Schematic for V2.0
    [KH-TYPE-C-16P--3DModel-STEP-269445.STEP, MSK12C02--3DModel-STEP-740413.STEP, MSK12C02.step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]
2026-05-03 Initial V2.0 Layout
    [3002.STEP, BAT-HLD-005-THM.step, SO-8_STM.step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]
2026-05-03 Change Button in Schematic and Footprint
    [CS1210F260.stp, business_card.kicad_pcb, business_card.kicad_sch]
2026-05-05 Initial Layout for V2.0
    [business_card.kicad_pcb, business_card.kicad_sch]
2026-05-06 Add NFC Antenna
    [business_card.kicad_pcb, business_card.kicad_sch]
2026-05-07 Adjust LED Matrix Size
    [business_card.kicad_pcb]
2026-05-07 Add Mouse Bites to Isolate Tooling Holes
    [business_card.kicad_pcb, business_card.kicad_sch]
2026-05-07 Move Components and Remove Unnecessary Silkscreen
    [business_card.kicad_pcb]
2026-05-15 Initial STM32 IOC File Setup
2026-05-16 Set Up DMA at 400Hz refresh rate
2026-05-25 Change Debug Interface Connector Size
    [business_card.kicad_pcb, business_card.kicad_sch]
2026-05-26 Set Up Power Supply Voltage Monitoring
2026-05-27 Add PushButton Inputs Using Interrupt Lines
2026-05-28 Add V1.0 Board Photos
2026-06-24 Set Up LED Screen DMA Transaction
2026-07-06 Add DMA Configuration and Remove USB
2026-08-30 Improve Button Input Handling
2026-08-31 Improve Interrupt Handling
2026-08-31 Fix Formatting and Debug Settings
    [main.c]
2026-09-01 Fix BOR level implementation
    [V1.X.ioc, main.c]
2026-09-08 Get Hardware V1.1 Ready For Production
    [3002.STEP, KH-TYPE-C-16P--3DModel-STEP-269445.STEP, MSK12C02--3DModel-STEP-740413.STEP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]

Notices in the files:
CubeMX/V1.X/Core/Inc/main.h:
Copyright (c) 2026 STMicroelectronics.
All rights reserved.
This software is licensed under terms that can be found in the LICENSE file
